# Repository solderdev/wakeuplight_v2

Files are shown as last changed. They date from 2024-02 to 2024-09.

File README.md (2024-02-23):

# wakeuplight_v2
ESP32 LED-strip wakeuplight with audio stream, NTP, etc.

Second version of my wakeuplight.

Uses an ESP32, N-channel MOSFETs with gate-drivers PWM-controlling multiple warm-white 24V-LED-strips.

Additionally an internet radio may wake you up.

Time is synchronized via NTP.

## Features

* PWA webinterface for easy control and live-feedback
* manually activate light and regulate intensity
* set fade start time and duration
* over-complicated fade algorithm for added smoothness
* store multiple WiFi credentials and connect / reconnect
* NTP time sync
* sunrise / sunset calculation and default intesity regulation
* store settings in NVM
* logging to serial out

## Build / run

* Build using PlatformIO
* F1 -> Tasks: Run task -> PlatformIO: Build filesystem image (esp32dev)
* F1 -> Tasks: Run task -> PlatformIO: Upload filesystem image (esp32dev)
* run program:
* PlatformIO: Build
* PlatformIO: Upload and Monitor

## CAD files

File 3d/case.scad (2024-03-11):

include <BOSL2/std.scad>

$fn=100;
OVERLAP = 0.1;

WALL_SIDE = 1.8;
WALL_AROUND_INSERT = 1.2;
WALL_BOTTOM = 1.5;
WALL_TOP = 1.5;
WALL_tol = 0.25;

EXTRA_SPACE_TOP_Y = 5.8;  // needed to insert PCB sandwitch in an angled motion

PCB_X = 113.1;
PCB_Y = 44.7;
PCB_Z = 1.6;
PCB_MNT_HOLE_EDGE_X = 3.2;  // from outer PCB edge
PCB_MNT_HOLE_EDGE_Y = [PCB_Y/2 - 9.3, -PCB_Y/2 + 9.3];  // from outer PCB edge
PCB_MNT_HOLE_MID_X = -PCB_X/2 + 61;  // from left PCB edge
PCB_MNT_HOLE_MID_Y = PCB_Y/2 - 3.3;  // from outer PCB edge
PCB_COMPONENTS_TOP = 18 + 3.4;  // account for hacky insert above audio jack
PCB_COMPONENTS_BOT = 8;
PCB_MOUNTS_TOL = 0.15;

POWER_IN_CENTER_OFF_X = 11.105;  // from left PCB edge
POWER_IN_X = 8.81 + 0.5;
POWER_IN_Z = 7 + 0.8;
POWER_IN_CENTER_OFF_Z = POWER_IN_Z/2 - PCB_MOUNTS_TOL - 0.1;

POWER_OUT_CENTER_OFF_X = 27;  // from left PCB edge
POWER_OUT_SPACING = 19.1;
POWER_OUT_NUM = 2;
POWER_OUT_X = 7.1*2 + 1 + 0.5;
POWER_OUT_Z = 10;
POWER_OUT_CENTER_OFF_Z = POWER_OUT_Z/2 - PCB_MOUNTS_TOL - 0.1;

CON_BTN_CENTER_OFF_X = 68.85;  // from left PCB edge
CON_BTN_X = 22.4 + 0.5;
CON_BTN_Z = 8.8 + 0.5;
CON_BTN_CENTER_OFF_Z = CON_BTN_Z/2 - PCB_MOUNTS_TOL - 0.1;

CON_USB_CENTER_OFF_X = 89.1;  // from left PCB edge
CON_USB_X = 15 + 0.5;
CON_USB_Z = 7.6 + 0.5;
CON_USB_CENTER_OFF_Z = -PCB_Z - CON_USB_Z/2 - PCB_MOUNTS_TOL + 0.1;

CON_AUDIO_CENTER_OFF_X = 108;  // from left PCB edge
CON_AUDIO_D = 6.5;
CON_AUDIO_X = CON_AUDIO_D + 0.1;
CON_AUDIO_Z = CON_AUDIO_X;
CON_AUDIO_CENTER_OFF_Z = 13 - PCB_MOUNTS_TOL - 0.1;

M3_HOLE_D = 3.4;
INSERT_M3_HOLE_D = 4.01 + 0.3;
INSERT_M3_D = 4.55;
INSERT_HEIGHT = 5.8;
INSERT_DEPTH_CASE = 15;
INSERT_DEPTH_PCB = INSERT_HEIGHT + 0.5;

// outside dimensions
CASE_EXTRA_X_LID_MOUNTS = 0;//(INSERT_M3_D + WALL_AROUND_INSERT)*2;
CASE_X = 2* WALL_SIDE + 2* WALL_tol + PCB_X + CASE_EXTRA_X_LID_MOUNTS;
CASE_Y = 2* WALL_SIDE + 2* WALL_tol + PCB_Y + EXTRA_SPACE_TOP_Y;
CASE_BOT_Z = WALL_BOTTOM + 2* WALL_tol + max(INSERT_DEPTH_PCB, PCB_COMPONENTS_BOT) + PCB_Z + PCB_COMPONENTS_TOP;
CASE_BOT_OFF_Z = -WALL_BOTTOM - WALL_tol - max(INSERT_DEPTH_PCB, PCB_COMPONENTS_BOT);  // bottom of case to bottom of PCB
CASE_ROUNDING_R = 3;
CASE_ROUNDING_INNER_R = 3;

TOP_reinforcement_xy = 1.6;
TOP_reinforcement_z = 1.6;

module dummy()
{
  // PCB
  translate([-PCB_X/2, PCB_Y/2, 1.57252/2]) rotate([0, 0, 0]) import("pcb.stl");
}

module cutout_front(dim_x, dim_z, round_r, offset_center_x, offset_center_z)
{
  translate([-PCB_X/2 + offset_center_x, -CASE_Y/2 + WALL_SIDE/2, -CASE_BOT_OFF_Z + PCB_Z + offset_center_z])
  {
    cuboid([dim_x, CASE_Y/2, dim_z], rounding=round_r, edges="Y", anchor=CENTER);
  }
}

module case_bottom()
{
  translate([0, EXTRA_SPACE_TOP_Y/2, CASE_BOT_OFF_Z])
  {
    difference()
    {
      // outer box
      cuboid([CASE_X, CASE_Y, CASE_BOT_Z], rounding=CASE_ROUNDING_R, edges="Z", anchor=BOTTOM);
      
      // inner cutout
      translate([0, 0, WALL_BOTTOM])
      difference()
      {
        // wide sides of PCB space plus extra on top
        cuboid([PCB_X + WALL_tol*2 + CASE_EXTRA_X_LID_MOUNTS, PCB_Y + EXTRA_SPACE_TOP_Y + WALL_tol*2, 1000], 
               rounding=CASE_ROUNDING_INNER_R, anchor=BOTTOM);
        
        // inner corners with M3 inserts
        // round side
        xcopies(spacing=CASE_X - WALL_SIDE*2 - INSERT_M3_D, n=2)
        ycopies(spacing=CASE_Y - WALL_SIDE*2 - INSERT_M3_D, n=2)
          cyl(h=1000, r=INSERT_M3_D/2 + WALL_AROUND_INSERT, center=false);
        
        // flat sides of corners
        xcopies(spacing=CASE_X - WALL_SIDE*2, n=2)
        ycopies(spacing=CASE_Y - WALL_SIDE*2, n=2)
        {
          cube([(INSERT_M3_D), (INSERT_M3_D + WALL_AROUND_INSERT)*2, 1000], center=true);
          cube([(INSERT_M3_D + WALL_AROUND_INSERT)*2, (INSERT_M3_D), 1000], center=true);
        }
        
        // PCB standoffs with inserts
        translate([0, -EXTRA_SPACE_TOP_Y/2, -CASE_BOT_OFF_Z - WALL_BOTTOM - PCB_MOUNTS_TOL])  // move just slightly under PCB
        {
          mirror_copy([1, 0, 0], offset=(PCB_X - PCB_MNT_HOLE_EDGE_X*2)/2)
            ycopies(PCB_MNT_HOLE_EDGE_Y)
              difference()
              {
                union() {
                  cyl(h=1000, d=INSERT_M3_D + WALL_AROUND_INSERT*2, anchor=TOP);
                  cube([10, INSERT_M3_D + WALL_AROUND_INSERT*2, 1000], anchor=TOP+LEFT);
                }
                translate([0, 0, OVERLAP])
                  cyl(h=INSERT_DEPTH_PCB + OVERLAP, d=INSERT_M3_HOLE_D, anchor=TOP);
              }
          
          // middle standoff
          translate([PCB_MNT_HOLE_MID_X, PCB_MNT_HOLE_MID_Y, 0])
            difference()
            {
              cyl(h=1000, d=INSERT_M3_D + WALL_AROUND_INSERT*2, anchor=TOP);
              translate([0, 0, OVERLAP])
                cyl(h=INSERT_DEPTH_PCB + OVERLAP, d=INSERT_M3_HOLE_D, anchor=TOP);
            } 
        }
      }
      
      // hack to make room for badly placed audio module
      translate([CASE_X/2 - WALL_SIDE - INSERT_M3_D/2 - WALL_AROUND_INSERT/2 - OVERLAP/2,
                  -CASE_Y/2 + WALL_SIDE + INSERT_M3_D/2 + WALL_AROUND_INSERT/2 + OVERLAP/2,
                  -CASE_BOT_OFF_Z])
        cube([INSERT_M3_D + WALL_AROUND_INSERT + OVERLAP, INSERT_M3_D + WALL_AROUND_INSERT + OVERLAP, CON_AUDIO_CENTER_OFF_Z+2], anchor=BOT);
      
      // M3 inserts to mount case top lid
      translate([0, 0, CASE_BOT_Z + OVERLAP])
        xcopies(spacing=CASE_X - WALL_SIDE*2 - INSERT_M3_D, n=2)
        ycopies(spacing=CASE_Y - WALL_SIDE*2 - INSERT_M3_D, n=2)
          cyl(h=INSERT_DEPTH_CASE + OVERLAP, d=INSERT_M3_HOLE_D, anchor=TOP);
      
      // power connector
      cutout_front(POWER_IN_X, POWER_IN_Z, round_r=0, offset_center_x=POWER_IN_CENTER_OFF_X, offset_center_z=POWER_IN_CENTER_OFF_Z);
      
      // power connector label
      text_depth = 0.5;  // imprint depth on sides
      text_h = text_depth + OVERLAP;  // height of subtractor
      translate([-PCB_X/2 + POWER_IN_CENTER_OFF_X, 
                  -CASE_Y/2 + text_depth/2, 
                  -CASE_BOT_OFF_Z + PCB_Z])
      {
        translate([-2, 0, -3]) rotate([90,0,0])
          linear_extrude(height=text_h, center=true)
            text("+", size=5, font="Liberation Sans:style=Bold", halign="center", valign="center", $fn=16);
                 
        translate([2, 0, -3]) rotate([90,0,0])
          linear_extrude(height=text_h, center=true)
            text("-", size=5, font="Liberation Sans:style=Bold", halign="center", valign="center", $fn=16);
      }
      
      // power out connectors
      xcopies(spacing=POWER_OUT_SPACING, n=POWER_OUT_NUM, sp=0)
      {
        cutout_front(POWER_OUT_X, POWER_OUT_Z, round_r=0, offset_center_x=POWER_OUT_CENTER_OFF_X, offset_center_z=POWER_OUT_CENTER_OFF_Z);
        
        translate([-PCB_X/2 + POWER_OUT_CENTER_OFF_X, 
                    -CASE_Y/2 + text_depth/2, 
                    -CASE_BOT_OFF_Z + PCB_Z])
        {
          translate([-5.8, 0, -3]) rotate([90,0,0]) linear_extrude(height=text_h, center=true)
              text("+", size=4, font="Liberation Sans:style=Bold", halign="center", valign="center", $fn=16);
          translate([-2.3, 0, -3]) rotate([90,0,0]) linear_extrude(height=text_h, center=true)
              text("-", size=4, font="Liberation Sans:style=Bold", halign="center", valign="center", $fn=16);
          translate([5.8, 0, -3]) rotate([90,0,0]) linear_extrude(height=text_h, center=true)
              text("-", size=4, font="Liberation Sans:style=Bold", halign="center", valign="center", $fn=16);
          translate([2.3, 0, -3]) rotate([90,0,0]) linear_extrude(height=text_h, center=true)
              text("+", size=4, font="Liberation Sans:style=Bold", halign="center", valign="center", $fn=16);
        }
      }
      
      // button connectors
      cutout_front(CON_BTN_X, CON_BTN_Z, round_r=0, offset_center_x=CON_BTN_CENTER_OFF_X, offset_center_z=CON_BTN_CENTER_OFF_Z);
      
      translate([-PCB_X/2 + CON_BTN_CENTER_OFF_X, 
                  -CASE_Y/2 + text_depth/2, 
                  -CASE_BOT_OFF_Z + PCB_Z])
      {
        translate([-5.8, 0, -3]) rotate([90,0,0]) linear_extrude(height=text_h, center=true)
            text("A-A-", size=3, font="Liberation Mono:style=Bold", halign="center", valign="center", $fn=16);
        translate([5.8, 0, -3]) rotate([90,0,0]) linear_extrude(height=text_h, center=true)
            text("B-B-", size=3, font="Liberation Mono:style=Bold", halign="center", valign="center", $fn=16);
      }
      
      // USB power out
      cutout_front(CON_USB_X, CON_USB_Z, round_r=0, offset_center_x=CON_USB_CENTER_OFF_X, offset_center_z=CON_USB_CENTER_OFF_Z);
      
      // line out
      cutout_front(CON_AUDIO_X, CON_AUDIO_Z, round_r=CON_AUDIO_D/2, offset_center_x=CON_AUDIO_CENTER_OFF_X, offset_center_z=CON_AUDIO_CENTER_OFF_Z);
    }
  }
}
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

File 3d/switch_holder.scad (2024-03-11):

include <BOSL2/std.scad>
//use <cherrymx.scad>

$fn=100;

wall = 1.0;
cutout_sidelen = 14;
switch_height = 9;  // below surface
rounding_sides = 1;
indent_width = 5;
indent_height = 2;
indent_offset_top_z = 2;
indent_depth = 0.5; // into wall

cable_height = 2;
cable_width = 4;
cable_tol = 0.15;

module hole_cable(orientation)
{
  hull()
  {
    translate([(cable_width - cable_height)/2, 0, cable_height/2 + cable_tol/2])
      cylinder(h=cutout_sidelen+wall, d=cable_height+cable_tol, orient=orientation);
    translate([-(cable_width - cable_height)/2, 0, cable_height/2 + cable_tol/2])
      cylinder(h=cutout_sidelen+wall, d=cable_height+cable_tol, orient=orientation);
  }
}

difference()
{
  // outer shell
  cuboid([cutout_sidelen + wall*2, cutout_sidelen + wall*2, switch_height + wall], rounding=rounding_sides, edges=["Z"], anchor=BOT);
  
  // cutout for switch
  translate([0, 0, wall])
    cube([cutout_sidelen, cutout_sidelen, switch_height + 0.1], anchor=BOT);
    
  // indents on sides for switch to clip in
  ycopies(cutout_sidelen - indent_height * sqrt(2) + indent_depth*2)
    translate([0, 0, wall + switch_height - indent_offset_top_z])
      xrot(45)
        cube([indent_width, indent_height, indent_height], center=true);
  
  // hole for cable in back of case
  translate([0, 0, wall])
    hole_cable(BACK);
    
  // hole for cable in bottom of case
  translate([0, cutout_sidelen/2 - (cable_height/2 + cable_tol/2), wall])
    hole_cable(DOWN);
  
  // debug
//  cube(100);
}

//*translate([0, 0, 23.4])
//  #CherryMX();

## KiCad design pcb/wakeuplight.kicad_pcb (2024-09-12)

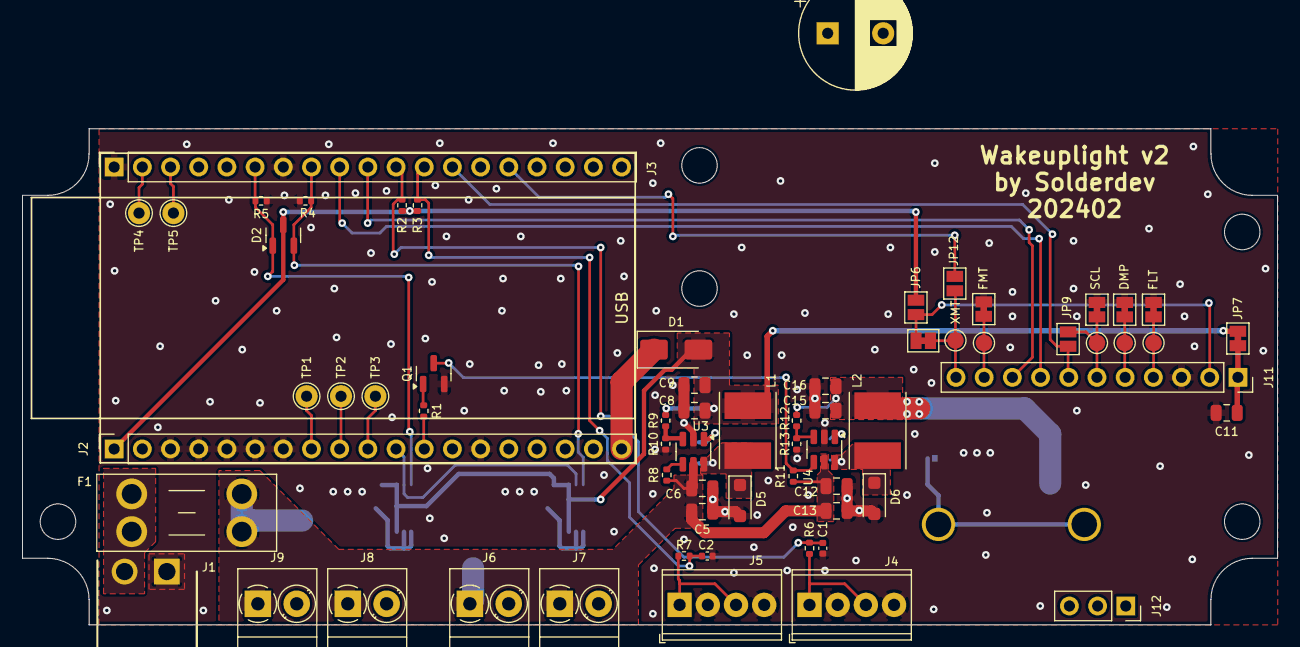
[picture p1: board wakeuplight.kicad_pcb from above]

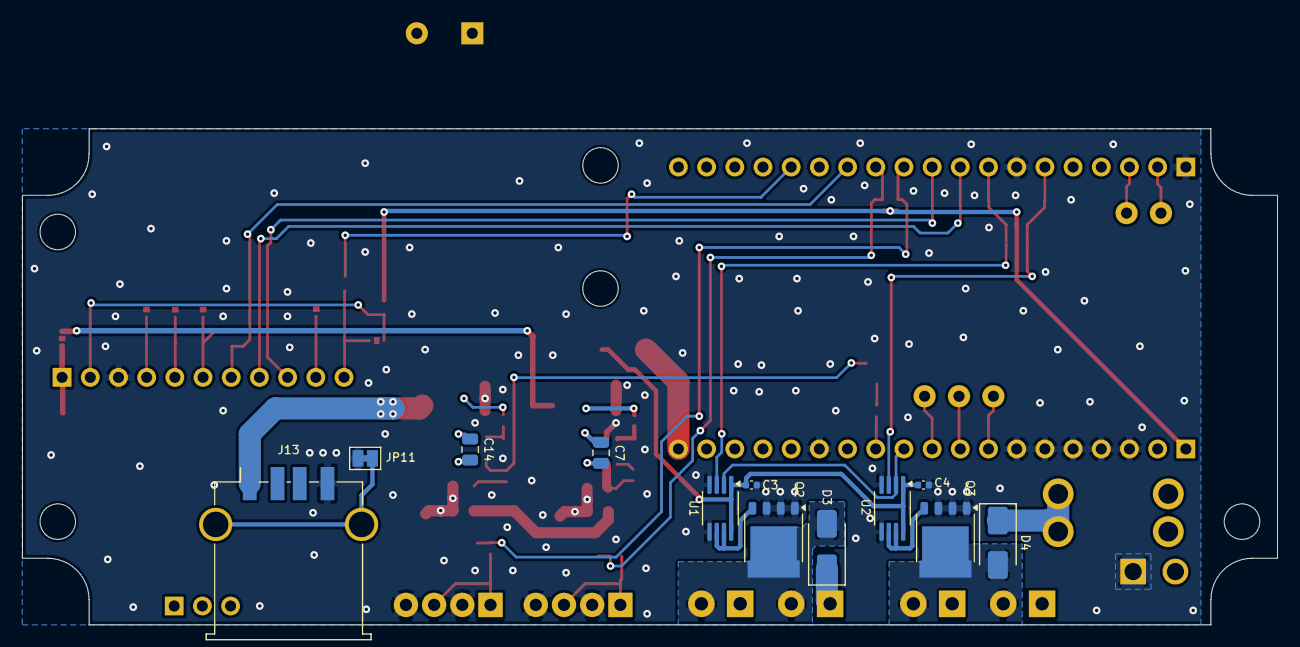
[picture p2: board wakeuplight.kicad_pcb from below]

Board: 2 copper layers, 113.1 x 44.7 mm, 82 parts (12 on the bottom side), 45 nets.

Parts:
C1, C2, C3, C4: 1uF 10V; C_0402_1005Metric
C5, C6, C12, C13: 1uF 35V; C_0805_2012Metric
C7, C14: 100nF 50V; C_0805_2012Metric
C8, C9, C11, C15, C16: 10uF 10V; C_0805_2012Metric
C17: ? uF; CP_Radial_D10.0mm_P5.00mm
D1, D3, D4: SS16_R2_00001 1A, 42V; D_SMA
D2: BAT54C; SOT-23
D5, D6: PMEG2020EH; D_SOD-123F
F1: Keystone_3568; Fuseholder_Blade_Mini_Keystone_3568
H1, H2, H3, H4, H7: MountingHole; MountingHole_3.2mm_M3_DIN965
J1: 691322310002; Wuerth_Term_3.81_1x2_691322310002
J2, J3: Conn_01x19; PinSocket_1x19_P2.54mm_Vertical
J4, J5: MPT 2,54; TerminalBlock_Phoenix_MPT-0,5-4-2.54_1x04_P2.54mm_Horizontal
J6, J7, J8, J9: MKDS 3.5mm; TerminalBlock_Phoenix_PT-1,5-2-3.5-H_1x02_P3.50mm_Horizontal
J11: PCM5102A Breakout; PinSocket_1x11_P2.54mm_Vertical
J12: Conn_01x03_Pin; PinSocket_1x03_P2.54mm_Vertical
J13: USB_A; USB_A_TE_292303-7_Horizontal
JP3, JP4, JP5, JP7, JP8, JP10, JP11: SolderJumper_2_Bridged; SolderJumper-2_P1.3mm_Bridged_Pad1.0x1.5mm
JP6, JP9, JP12: SolderJumper_2_Open; SolderJumper-2_P1.3mm_Open_Pad1.0x1.5mm
L1, L2: 22uH SRN5040-220M; L_Taiyo-Yuden_NR-50xx_HandSoldering
Q1: T2N7002BK; SOT-23
Q2, Q3: PSMN1R2-30YLC; LFPAK56
R1, R6, R7: 1k; R_0402_1005Metric
R2, R3: 100k; R_0402_1005Metric
R4, R5, R10, R13: 10k; R_0402_1005Metric
R8, R11: 200k; R_0402_1005Metric
R9, R12: 54k9; R_0402_1005Metric
TP1, TP2, TP3, TP4, TP5: TestPoint; TestPoint_THTPad_D2.0mm_Drill1.0mm
TP6, TP7, TP8, TP9, TP10: TestPoint; TestPoint_Pad_D1.5mm
U1, U2: MCP14A0302; MSOP-8_3x3mm_P0.65mm
U3, U4: LMR16006YQ; SOT-23-6

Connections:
+3V3: D2.3, J2.1, JP6.1 (A), R2.2, R3.2
+5V: C3.1, C4.1, C8.1, C9.1, D1.2 (A), JP7.1 (A), L1.2, R9.1, U1.1 (VDD), U1.8 (VDD), U2.1 (VDD), U2.8 (VDD)
+24V: C5.1, C6.1, C12.1, C13.1, C17.1, D3.1 (K), D4.1 (K), F1.2, J6.1, J7.1, J8.1, J9.1, R8.1, R11.1, U3.5 (VIN), U4.5 (VIN)
/5V_audio: C15.1, C16.1, J13.1 (VBUS), L2.2, R12.1
/EN_bottom: D2.1, J3.6, R5.2, U2.3 (EN)
/EN_top: D2.2, J3.8, R4.2, U1.3 (EN)
/I2S_BCLK: J3.13, J11.7, JP9.2 (B)
/I2S_DOUT: J3.9, J11.8
/I2S_WS: J3.10, J11.9
/PCM5102A/DMP: J11.5, JP4.2 (B), TP7.1
/PCM5102A/FLT: J11.4, JP3.2 (B), TP6.1
/PCM5102A/FMT: J11.10, JP10.2 (B), TP10.1
/PCM5102A/PCM_3V3: J11.2, JP6.2 (B), JP8.1 (A)
/PCM5102A/PCM_5V: C11.1, J11.1, JP7.2 (B)
/PCM5102A/SCL: J11.6, JP5.2 (B), JP9.1 (A), TP8.1
/PCM5102A/XMT: J11.11, JP8.2 (B), JP12.2 (B), TP9.1
/PWM_sig: J2.11, U1.2 (IN), U2.2 (IN)
/button_1: C1.1, J3.11, R2.1, R6.1
/button_2: C2.1, J3.12, R3.1, R7.1
/mute: J3.15, JP12.1 (A)
/regulator_5v/~SHDN: R8.2, U3.4 (~SHDN)
/regulator_5v_audio/~SHDN: Q1.3 (D), R11.2, U4.4 (~SHDN)
/~EN_audio: J2.12, R1.2
GND: C1.2, C2.2, C3.2, C4.2, C5.2, C6.2, C8.2, C9.2, C11.2, C12.2, C13.2, C15.2, C16.2, C17.2, D5.2 (A), D6.2 (A), J1.1, J2.3, J2.4, J2.5, J2.6, J2.7, J2.14, J3.1, J3.7, J4.2, J4.4, J5.2, J5.4, J11.3, J13.4 (GND), JP3.1 (A), JP4.1 (A), JP5.1 (A), JP10.1 (A), JP11.2 (B), Q1.2 (S), Q2.1 (S), Q2.2 (S), Q2.3 (S), Q3.1 (S), Q3.2 (S), Q3.3 (S), R4.1, R5.1, R10.2, R13.2, U1.4 (GND), U1.5 (GND), U2.4 (GND), U2.5 (GND), U3.2 (GND), U4.2 (GND)
unnamed: D1.1 (K), J2.19
unnamed: D3.2 (A), J6.2, J7.2, Q2.5 (D)
unnamed: D4.2 (A), J8.2, J9.2, Q3.5 (D)
unnamed: C7.2, D5.1 (K), L1.1, U3.6 (SW)
unnamed: C14.2, D6.1 (K), L2.1, U4.6 (SW)
unnamed: F1.1, J1.2
unnamed: J2.8, TP1.1
unnamed: J2.9, TP2.1
unnamed: J2.10, TP3.1
unnamed: J3.2, TP4.1
unnamed: J3.3, TP5.1
unnamed: J4.1, J4.3, R6.2
unnamed: J5.1, J5.3, R7.2
unnamed: J13.5 (Shield), JP11.1 (A)
unnamed: Q1.1 (G), R1.1
unnamed: Q2.4 (G), U1.6 (OUT), U1.7 (OUT)
unnamed: Q3.4 (G), U2.6 (OUT), U2.7 (OUT)
unnamed: C7.1, U3.1 (CB)
unnamed: R9.2, R10.1, U3.3 (FB)
unnamed: C14.1, U4.1 (CB)
unnamed: R12.2, R13.1, U4.3 (FB)

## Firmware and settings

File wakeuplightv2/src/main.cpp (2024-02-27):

// #define CORE_DEBUG_LEVEL  ARDUHAL_LOG_LEVEL_DEBUG

#include <Arduino.h>
#include <nvs_flash.h>
#include "WebInterface.hpp"
#include "Pins.hpp"
#include "LEDControl.hpp"
#include "AlarmControl.hpp"
#include "InternetRadio.hpp"

#include "time.h"

#include "esp32-hal-log.h"
#include "esp_sntp.h"

WebInterface *web_interface;
LEDControl *led_control;
InternetRadio *internet_radio;
AlarmControl *alarm_control;

static uint32_t systime_multiplier = 1;

void systime_init()
{
  systime_multiplier = 80000000 / getApbFrequency();
}

unsigned long IRAM_ATTR systime_ms()
{
  return (unsigned long) ((esp_timer_get_time() * systime_multiplier) / 1000ULL);
}

void setup()
{
  setCpuFrequencyMhz(80);
  systime_init();

  esp_log_level_set("*", ESP_LOG_DEBUG);

  // COMPLETELY ERASE NVS
  // nvs_flash_erase(); // erase the NVS partition and...
  // nvs_flash_init(); // initialize the NVS partition.
  // while(true);

  Serial.begin(115200);
  Serial.setDebugOutput(true);
  delay(2000);
  log_d("Hi there! Booting now..");
  log_d("CPU clock: %u MHz / using systime multiplier %u with ApbFrequency %u", getCpuFrequencyMhz(), systime_multiplier, getApbFrequency());
  
  led_control = new LEDControl(Pins::pwm1, MCPWM_UNIT_0, Pins::en_top, Pins::en_bottom);
  internet_radio = new InternetRadio();
  
  alarm_control = new AlarmControl(led_control);

  web_interface = new WebInterface(alarm_control);

  // TODO audio
  pinMode(Pins::disable_audio_pwr, OUTPUT);
  digitalWrite(Pins::disable_audio_pwr, HIGH);

  // change NTP update interval
  sntp_set_sync_interval(1 * 60 * 60 * 1000UL); // 1 hours

  // time-zone needs to be set manually, otherwise DST switch date is wrong
  // by https://werner.rothschopf.net/microcontroller/202103_arduino_esp32_ntp_en.htm
  configTime(0, 0, "time.metrologie.at");
  // list of TZ strings: https://github.com/nayarsystems/posix_tz_db/eblob/master/zones.csv
  setenv("TZ", "CET-1CEST,M3.5.0,M10.5.0/3", 1);           // Set environment variable with your time zone
  tzset();
}

void loop()
{
  internet_radio->loop();

  // vTaskDelay(pdMS_TO_TICKS(5551));
  // log_d("ON");
  // led_control->setOnMode();
  // vTaskDelay(pdMS_TO_TICKS(3000));
  // log_d("Off");
  // led_control->setOffMode();

  // struct tm timeinfo;
  // if(!getLocalTime(&timeinfo, 0)){
  //   log_w("Failed to obtain time");
  // }
  // else
  //   log_d("%04u-%02u-%02u %02u:%02u:%02u", 
  //         1900 + timeinfo.tm_year, timeinfo.tm_mon, timeinfo.tm_mday, 
  //         timeinfo.tm_hour, timeinfo.tm_min, timeinfo.tm_sec);

  // log_d("systime: %u", systime_ms());
}

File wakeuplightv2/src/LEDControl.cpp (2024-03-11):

#include "LEDControl.hpp"
#include "Storage.hpp"

// https://forum.arduino.cc/t/esp32-mcpwm-trigger/907542/9
// https://github.com/espressif/esp-idf/blob/master/examples/peripherals/mcpwm/mcpwm_bdc_speed_control/main/mcpwm_bdc_control_example_main.c
// alternative (not exact): https://github.com/khoih-prog/ESP32_PWM
// alternative to switch off with one-shot: https://demo-dijiudu.readthedocs.io/en/latest/api-reference/system/esp_timer.html


LEDControl::LEDControl(uint8_t pwm_pin, mcpwm_unit_t mcpwm_unit_id, uint8_t en_top_pin, uint8_t en_bottom_pin) :
  mcpwm_unit_(mcpwm_unit_id), 
  pwm_pin(pwm_pin),
  en_top_pin(en_top_pin),
  en_bottom_pin(en_bottom_pin)
{
  this->frequency_hz_ = 600;
  this->duty_percent_ = 50.0f;

  pinMode(en_top_pin, OUTPUT);
  pinMode(en_bottom_pin, OUTPUT);
  digitalWrite(en_top_pin, LOW);
  digitalWrite(en_bottom_pin, LOW);
  
  log_d("init mcpwm driver");
  this->updateTiming(this->frequency_hz_, this->duty_percent_);
  this->setOffMode();
}

void LEDControl::updateTiming(uint32_t frequency_hz, float duty_percent)
{
  if (frequency_hz > 100 && frequency_hz < 30000 &&
      duty_percent > 0.0 && duty_percent < 100.0)
  {
    // do not re-apply same values
    if (this->mode == LEDMODE_PWM && this->frequency_hz_ == frequency_hz && this->duty_percent_ == duty_percent)
      return;
  }
  else
  {
    log_e("ERR Invalid frequency: %u  duty-cycle: %f", frequency_hz, duty_percent);
    return;
  }

  log_i("Setting frequency: %u", frequency_hz);
  log_i("Setting duty-cycle: %f", duty_percent);

  vTaskSuspendAll();

  if (this->mode != LEDMODE_PWM || this->frequency_hz_ != frequency_hz)
  {
    mcpwm_set_duty(this->mcpwm_unit_, MCPWM_TIMER_0, MCPWM_GEN_A, duty_percent);  // 100.0f - 
    mcpwm_gpio_init(this->mcpwm_unit_, MCPWM0A, this->pwm_pin);

    mcpwm_config_t pwm_config = {
        .frequency = frequency_hz,
        .cmpr_a = 0,
        .cmpr_b = 0,
        .duty_mode = MCPWM_DUTY_MODE_0,
        .counter_mode = MCPWM_DOWN_COUNTER,
    };
    mcpwm_init(this->mcpwm_unit_, MCPWM_TIMER_0, &pwm_config);

    mcpwm_set_duty_type(this->mcpwm_unit_, MCPWM_TIMER_0, MCPWM_GEN_A, MCPWM_DUTY_MODE_0);

    // activate timer output
    mcpwm_set_timer_sync_output(this->mcpwm_unit_, MCPWM_TIMER_0, MCPWM_SWSYNC_SOURCE_TEZ);
    digitalWrite(en_top_pin, HIGH);
    digitalWrite(en_bottom_pin, HIGH);
  }

  mcpwm_set_duty(this->mcpwm_unit_, MCPWM_TIMER_0, MCPWM_GEN_A, duty_percent);  // 100.0f - 
  // mcpwm_set_frequency(this->mcpwm_unit_, MCPWM_TIMER_0, frequency_hz);
  
  // set PWM-mode
  this->mode = LEDMODE_PWM;

  this->frequency_hz_ = frequency_hz;
  this->duty_percent_ = duty_percent;
  
  xTaskResumeAll();
}

uint32_t LEDControl::getFrequencyHz(void)
{
  return this->frequency_hz_;
}

float LEDControl::getDutyPercent(void)
{
  return this->duty_percent_;
}

LEDControl::LEDMode_t LEDControl::getMode(void)
{
  return this->mode;
}

void LEDControl::setOnMode(void)
{
  if (this->mode != LEDMODE_ON) {
    this->mode = LEDMODE_ON;
    mcpwm_set_signal_high(this->mcpwm_unit_, MCPWM_TIMER_0, MCPWM_GEN_A);
    digitalWrite(en_top_pin, HIGH);
    digitalWrite(en_bottom_pin, HIGH);
  }
}

void LEDControl::setOffMode(void)
{
  if (this->mode != LEDMODE_OFF) {
    this->mode = LEDMODE_OFF;
    mcpwm_set_signal_low(this->mcpwm_unit_, MCPWM_TIMER_0, MCPWM_GEN_A);
    digitalWrite(en_top_pin, LOW);
    digitalWrite(en_bottom_pin, LOW);
  }
}

void LEDControl::setPwmMode(void)
{
  this->updateTiming(this->frequency_hz_, this->duty_percent_);
}

void LEDControl::setFrequency(uint32_t frequency)
{
  this->updateTiming(frequency, this->duty_percent_);
}

void LEDControl::setDutyCycle(float duty_cycle)
{
  if (duty_cycle >= 100.0f)
    this->setOnMode();
  else if (duty_cycle > 0.0f)
    this->updateTiming(this->frequency_hz_, duty_cycle);
  else
    this->setOffMode();
}

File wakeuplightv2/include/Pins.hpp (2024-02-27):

#pragma once

#include <Arduino.h>

class Pins
{
public:
  static constexpr uint32_t pwm1 = 27;
  static constexpr uint32_t en_bottom = 21;
  static constexpr uint32_t en_top = 19;
  static constexpr uint32_t button_1 = 17;
  static constexpr uint32_t button_2 = 16;
  static constexpr uint32_t disable_audio_pwr = 14;
  static constexpr uint32_t i2s_dout = 18;
  static constexpr uint32_t i2s_bclk = 4;
  static constexpr uint32_t i2s_lrc = 5;
};

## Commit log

2024-01-08 work on pcb
    [max98357a.kicad_sch, pcm5102a.kicad_sch, power_out.kicad_sch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]
2024-01-21 work on PCB: line out + power done ; removed amplifier from board
    [max98357a.kicad_sch, pcm5102a.kicad_sch, power_out.kicad_sch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]
2024-02-02 PCB done
    [pcm5102a.kicad_sch, power_out.kicad_sch, regulator_5v.kicad_sch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]
2024-02-04 added draft of case design
    [case.scad]
2024-02-23 case: fixed cutouts for audio module ; added middle PCB standoff
    [case.scad]
2024-02-26 added FET-driver enable pins for basic operation
2024-02-27 included schreibfaul1/ESP32-audioI2S library and fought to squeeze it in ROM
    [partition_table.csv]
2024-02-28 PCB: renamed "EN_audio" to "~EN_audio" ; added input capacitor (PSU noise) ; fixed mirrored MOSFET
    [wakeuplight.kicad_pcb, wakeuplight.kicad_sch]
2024-03-11 case: modified text on top
    [case.scad]
2024-03-11 changed LED parameters
2024-03-11 added case for cherry-mx switch
    [switch_holder.scad]
2024-09-12 moved to Kicad 8
    [max98357a.kicad_sch, pcm5102a.kicad_sch, power_out.kicad_sch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]
